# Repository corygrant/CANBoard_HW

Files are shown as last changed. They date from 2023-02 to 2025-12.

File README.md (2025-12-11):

# CANBoard_HW
CANBoard is a simple CAN enabled IO board, specifically designed to be used in devices like steering wheels/button boxes/panels/etc.

* 8 digital inputs
    * Ground switching
* 5 analog inputs
    * 5V max
* 4 digital outputs
    * Low side switch (open collector)
    * 0.5A max each
* STM32F303K8
* KiCad 7.0.0

# Goals
- Create a low cost device that my friends and I can use in our project cars
- Use components that are easily soldered by hand (hence 0805) and are preferably from my stock of frequently used parts (ex: LD1117S33CTR)
- Share my work with others for reference, inspiration or collaboration. 

If this project does help you in any way, I'd appreciate a message!

# [Store](https://dingo-electronics.square.site/product/canboard/3)

# Disclaimer
Please note that this product has been designed by a hobbyist, not a professional. It is intended for off-road and testing use only. Users should operate the product at their own discretion and risk. The designer explicitly disclaims any responsibility for damage or injury that may result from the use of this product.

# Schematic
[Schematic PDF](/Export/V2/CANBoard_HW_V2.pdf)

# DBC

DBC file can be found [here](https://github.com/corygrant/CANBoard_FW/tree/main/dbc)

# BOM

[Interactive BOM](https://htmlpreview.github.io/?https://github.com/corygrant/CANBoard_HW/blob/main/docs/bom/ibom.html)

# Jumpers
**CAN Term** : Soldering this jumper enables the 120 ohm terminating resistor across CANL/CANH

**CAN ID Jumpers 1 and 2** : Soldering these jumpers allows different base CAN IDs to be selected when using multiple CANBoards in the same bus
| 1 | 2 | Base CAN ID (Hex)|
| --- | --- | ----- |
| Open | Open | 0x640 |
| Closed | Open | 0x650 |
| Open | Closed | 0x660 |
| Closed | Closed | 0x670 |

# Firmware
[CANBoard firmware](https://github.com/corygrant/CANBoard_FW)

# Updating Firmware
Use [Tag Connect TC2030 cable](https://www.tag-connect.com/product/tc2030-ctx-nl-stdc14-for-use-with-stm32-processors-with-stlink-v3) 

# Images
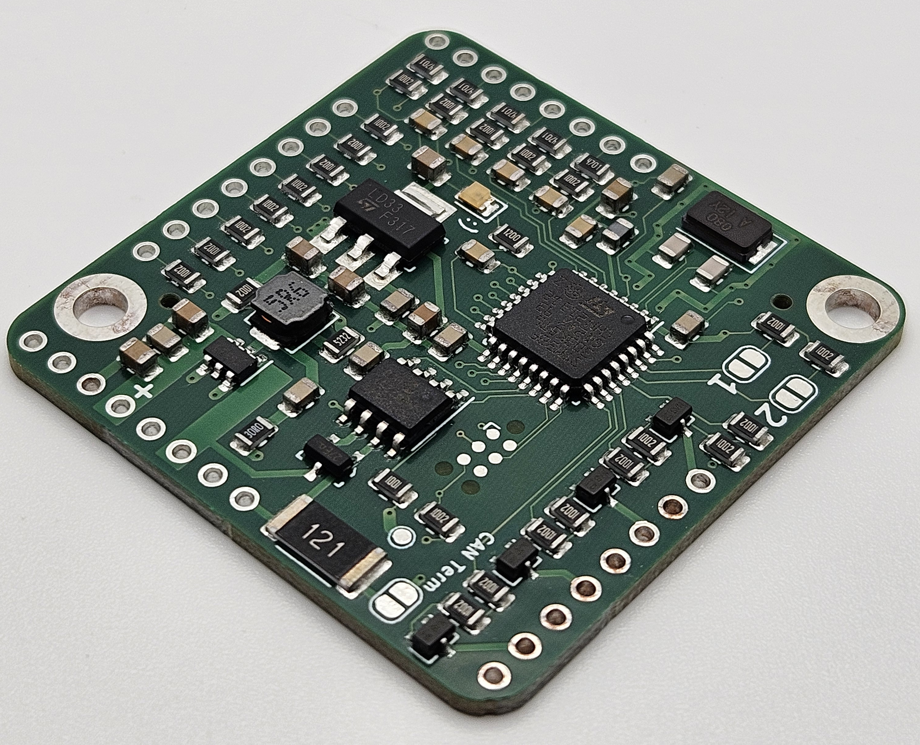
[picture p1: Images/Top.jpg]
Top


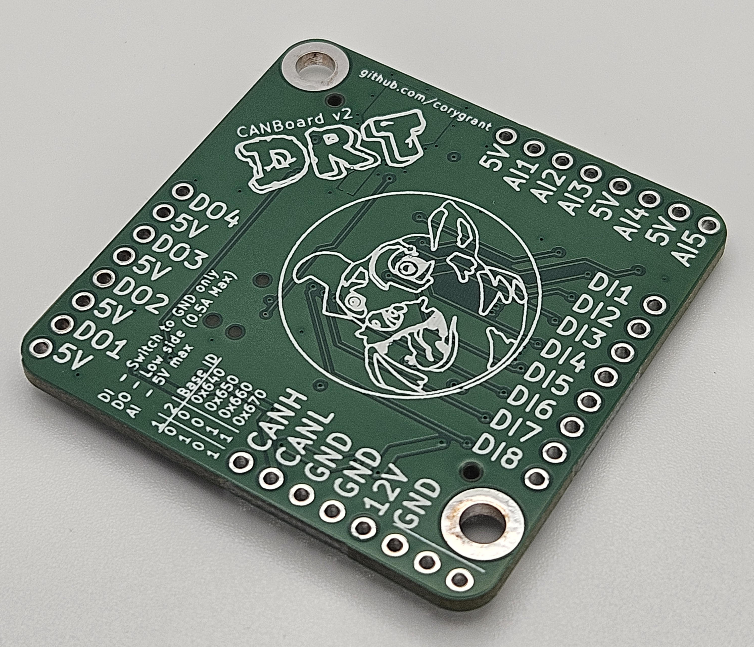
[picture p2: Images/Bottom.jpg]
Bottom


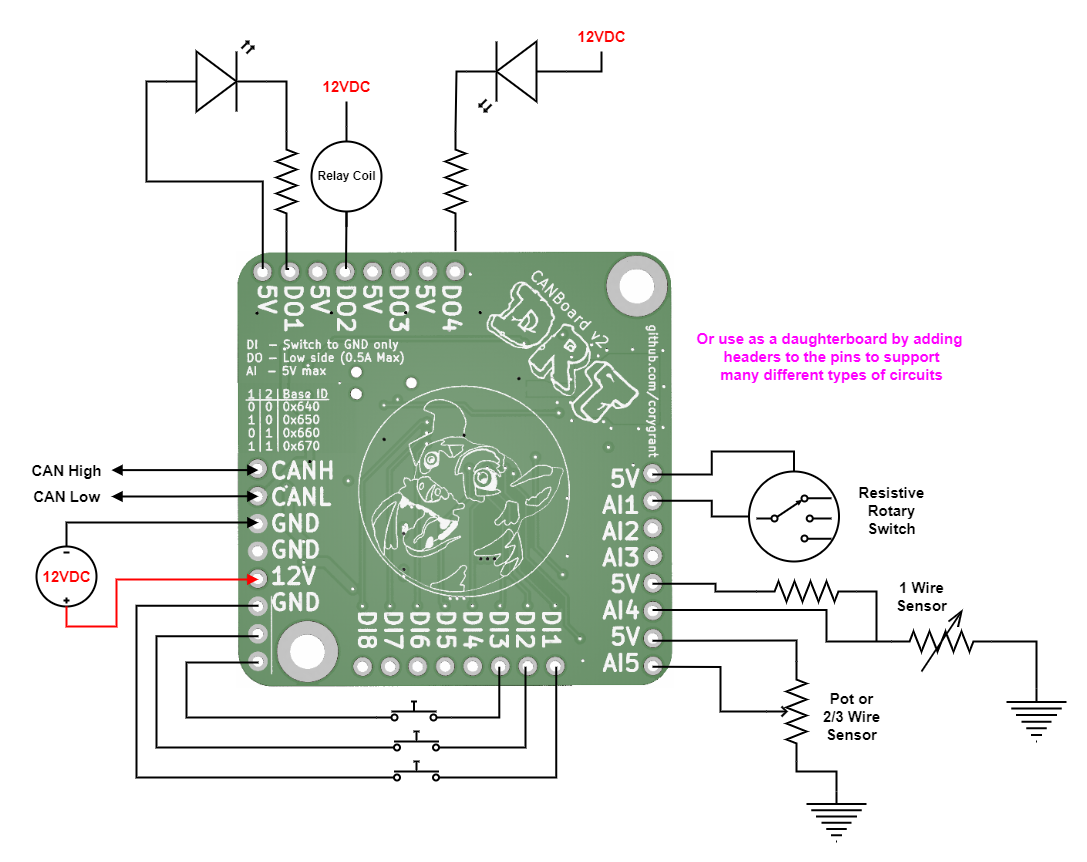
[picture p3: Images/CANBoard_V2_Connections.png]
Connections


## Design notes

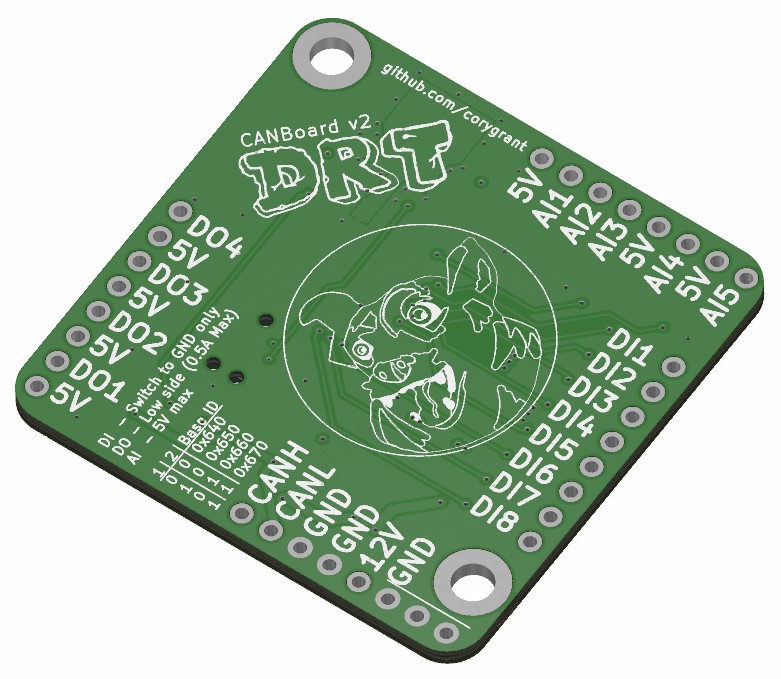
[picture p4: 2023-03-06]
Images/CANBoard_Bottom.jpg

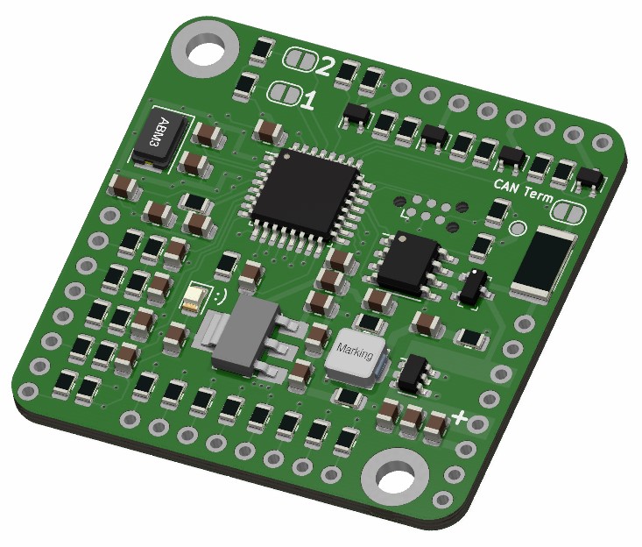
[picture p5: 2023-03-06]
Images/CANBoard_Top.jpg

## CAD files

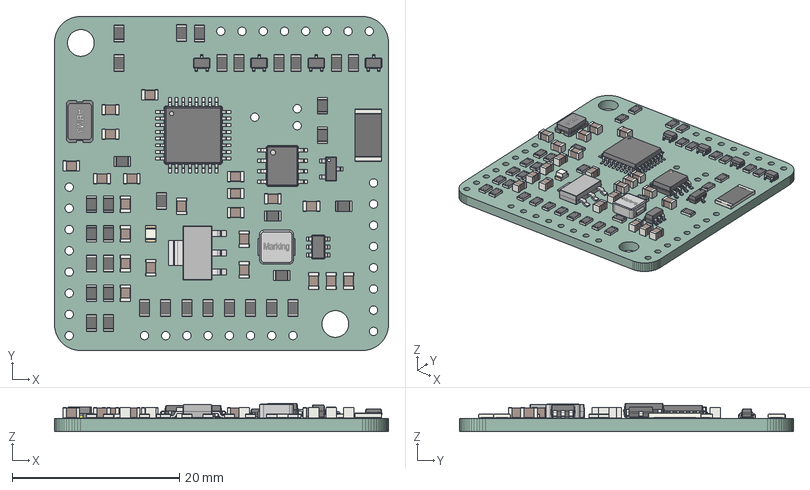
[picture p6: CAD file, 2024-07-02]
Export/V2/CANBoard_V2.step
40.0 x 40.0 x 3.38 mm
PCB

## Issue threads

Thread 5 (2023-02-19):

we have JLC BOM but not JLC placement file

rusefillc, 2023-02-19:
JLCPCB assembly takes gerbers, BOM and CPL for placement file

looks like placement file could be missing?

I know there is a minor drama between kicad export and JLC formats I vaguely remember people have to edit columns manually or use magic scripts let me know if I should poke people for more details

Closed 2023-02-19.

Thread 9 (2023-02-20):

Sad face: BOM not complete or JLC bug?

rusefillc, 2023-02-20:
JLC does not show LED and some random components are missing like digital resistors and output transistors? Is that a JLC render error or BOM is not full?

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

rusefillc, 2023-02-20:
PS: XLS file format is evil, CSV so much cooler for BOM - no need for weird tools and better git diffs

rusefillc, 2023-02-21:
```
Hi Andrey ,

Hope this mail finds you well.

After checking, unfortunately,  those components for the assembly had already been prepared on 2023-02-20.

In this case, I'm afraid it's just too late to cancel the assembly now due to process problem.

Please check if you could hand solder the missing parts by yourself this time?

Many thanks for your kind understanding.

Best regards,

Patrick
```

Closed 2023-02-21.

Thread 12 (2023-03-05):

Something EN pin

rusefillc, 2023-03-05:
@corygrant knows

corygrant, 2023-03-06:
One of the PCBs @rusefillc got from JLCPCB had a strange issue where the EN pin on the TPS56339DDCR (U1) buck converter had a 2mohm resistance to ground.
The EN pin should be completely floating (see section 7.3.2 of the datasheet).
This led to lots of power issues:
- Power not turning on
- Power fluctuating
- Lots of noise from the board
- Power only turning on when touching the EN pin with my finger

To fix this I cut and removed the pin and now the power is stable.
I'll update the PCB to remove the pad for EN (pin 5).

Closed 2023-03-06.

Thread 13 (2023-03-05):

blinking status LED

rusefillc, 2023-03-05:
Between #12 and else a blinking LED gives very clear confirmation of life

rusefillc, 2023-03-05:
Would that mean going to next pin count package?

corygrant, 2023-03-06:
Yes currently with the LQFP package we're maxed out on outputs

Closed 2024-07-17.

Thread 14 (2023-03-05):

By the way why F3?

rusefillc, 2023-03-05:
why F3 not F103 or else?

rusefillc, 2023-03-05:
Reasons I am asking:
* I am unhappy with $11.21 price
* I am unhappy with availability - note zero stock today assuming I search right

https://jlcpcb.com/partdetail/Stmicroelectronics-STM32F303K8T6/C118318

corygrant, 2023-03-06:
I can't remember exactly why I selected the F3.
Most likely because:
- The original design was done in fall 2020, so F3 stock wasn't an issue
- I had a handful of F303K8 leftover from another project

Lately I've been noticing some STM32s are easier to get than others and their product line is usually very pin compatible.
I'll see if there's an alternative part that could be easily swapped with no PCB changes.
If not, we can talk about updating to another part number. Possibly with more pins.

rusefillc, 2023-03-06:
> some STM32s are easier to get than others and their product line is usually very pin compatible.

let me mention "function-compatible replacements" i.e. clones
* TL,DR: at the moment I am very impressed with Geehy APM32 which JLCPCB has many

* at the pike of chip shortage we've tried GD32F1 - those needed a few lines of changes in the HAL. while it's only few lines it takes someone extremely highly qualified to locate what few lines to adjust. I've attempted to flash GD32F4 with as-is rusEFI and it did NOT fire up. overall GD32 is known to be close but not compatible
* now comes Geehy APM32. Two data points for those
- i know an automotive produce where they have simply replaced stm32f4 with apm32f4 and they claim zero firmware changes
- my own testing so far rusEFI firmware has started on apm32f4 and even USB connectivity was running! well, at the moment we've only tested flash, GPIO and USB but that's quite impressive

that's for apm32f4 open question how that translates to apm32f1 also open question why I am so fascinated by those alternatives. I guess I am addicted to the $2 price tag.

corygrant, 2023-03-06:
It seems like we're starting to come up out of the part shortage pit of despair, so hopefully JLC/LCSC will have things in stock soon.

Once you filter the ST catalog by LQFP32 and CAN you're left with only a couple of options, but most of them are available in the US:
- STM32F303K6 ($7.19)
- STM32F303K8 ($6.85)
- STM32F334K6 ($6.85)
- STM32F334K8 ($6.62)

Maybe ST is giving Digikey/Mouser/etc. preference and shipping to them first?
I think once the inventory starts hitting LCSC their prices will go down to similar levels.

pknetworksolutions, 2023-03-18:
Just got my board prep, with all the components needed. Just fill up your parts library and you can use them after that for the assembly

Luckey1996, 2024-01-17:
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

I was designing my product by using APM32F003 to replace STM8 and turns out the result was good. I have the same feeling that why not using Geehy with a extremely low price and good compatibility. Do you use already APM32F1 on your design and production? I want to know whether there are anything I need to prepare before the Mass Production. Look forward to your reply.

rusefillc, 2024-01-17:
> Do you use already APM32F1 on your design and production?

with stm32f4 prices going down at this point I am back to 100% stm32
* lack of USB DFU is a usability pain
* what we've designed as most budget unit turned to be unreliable with apm32f4 while stm32f4 is happy no idea what's root cause

Closed 2024-07-17.

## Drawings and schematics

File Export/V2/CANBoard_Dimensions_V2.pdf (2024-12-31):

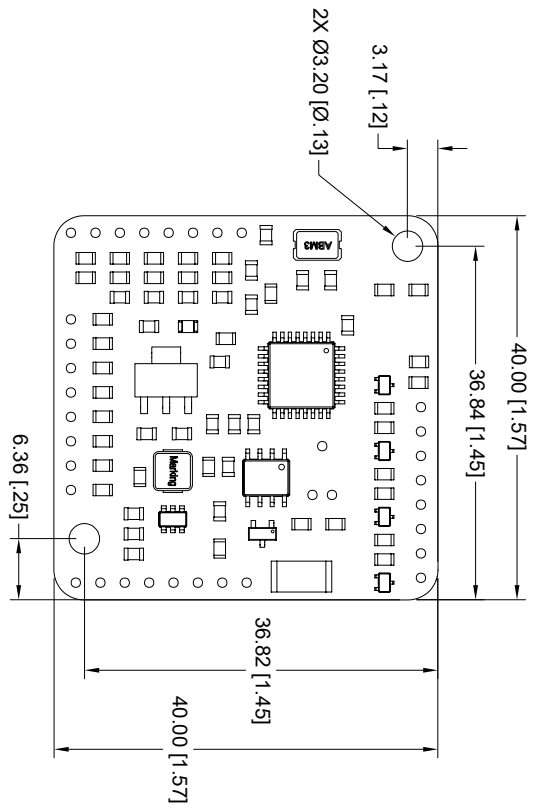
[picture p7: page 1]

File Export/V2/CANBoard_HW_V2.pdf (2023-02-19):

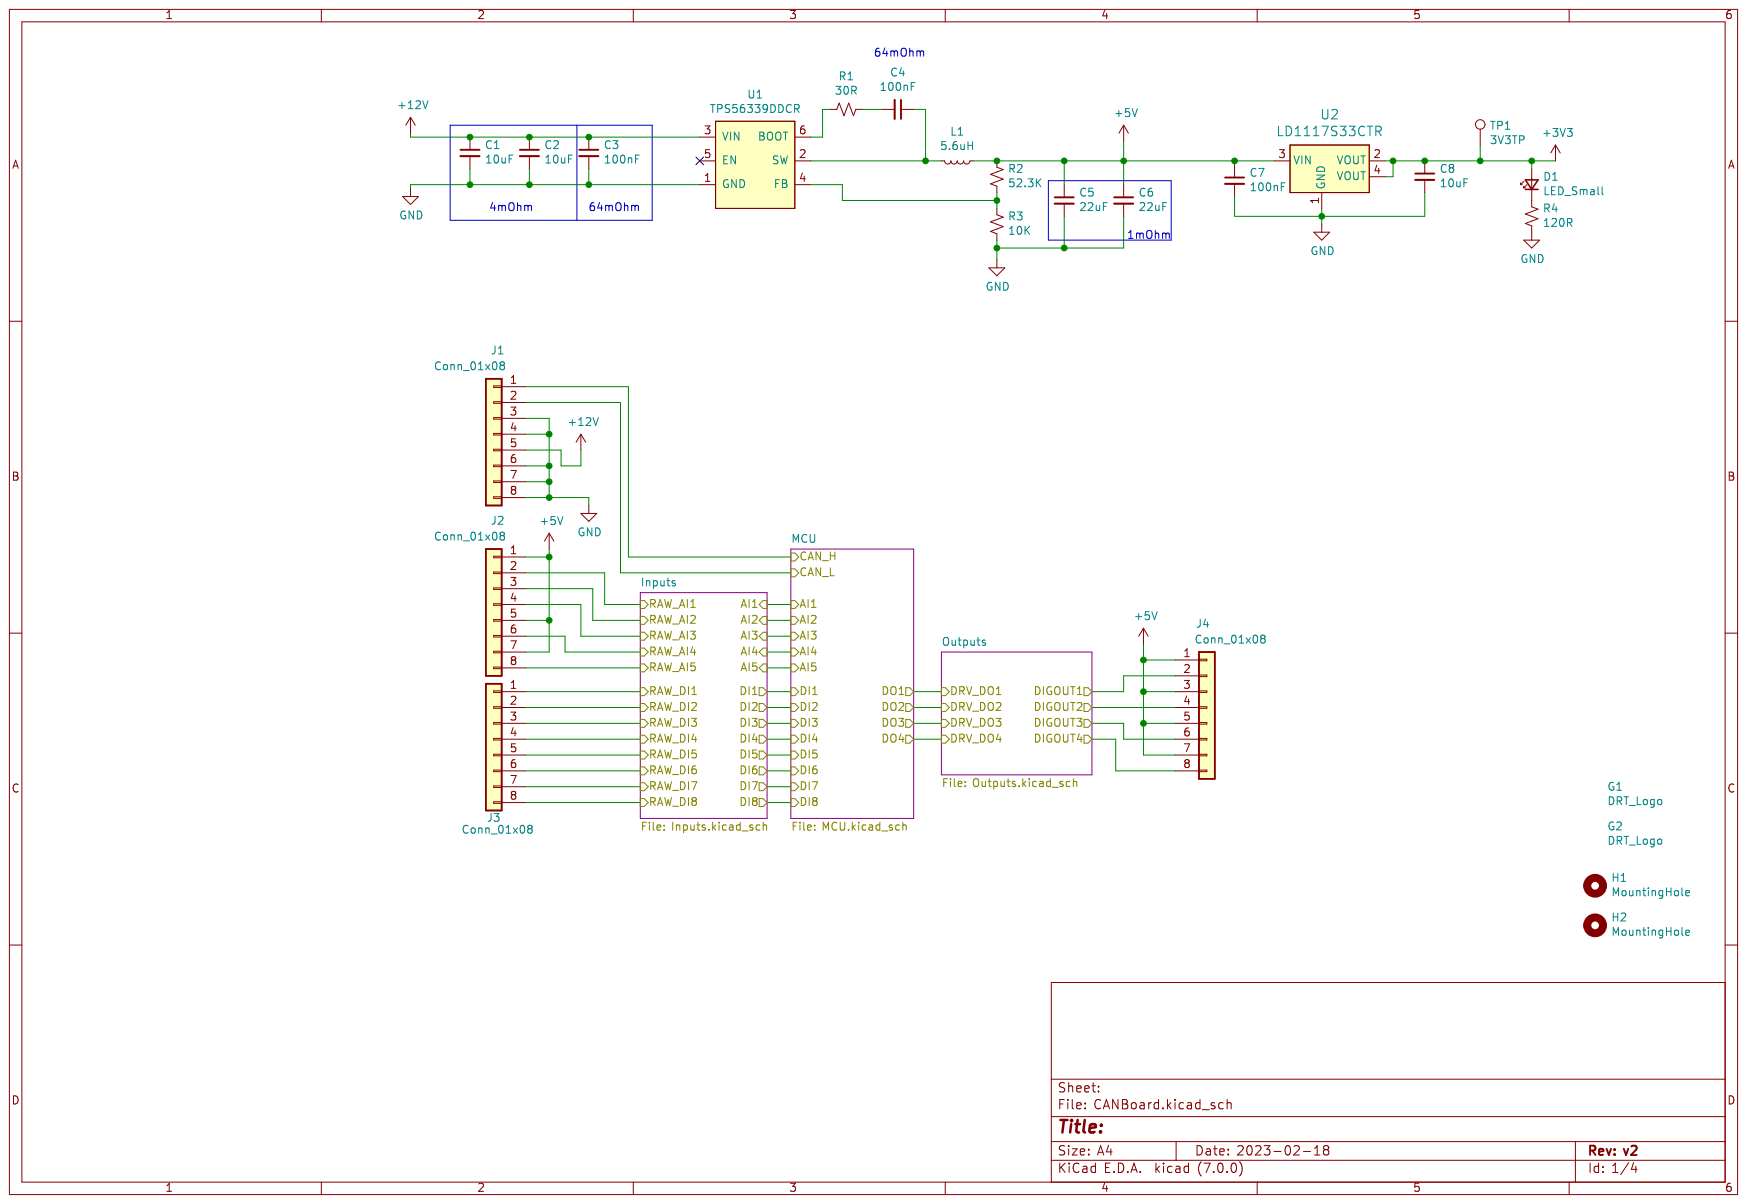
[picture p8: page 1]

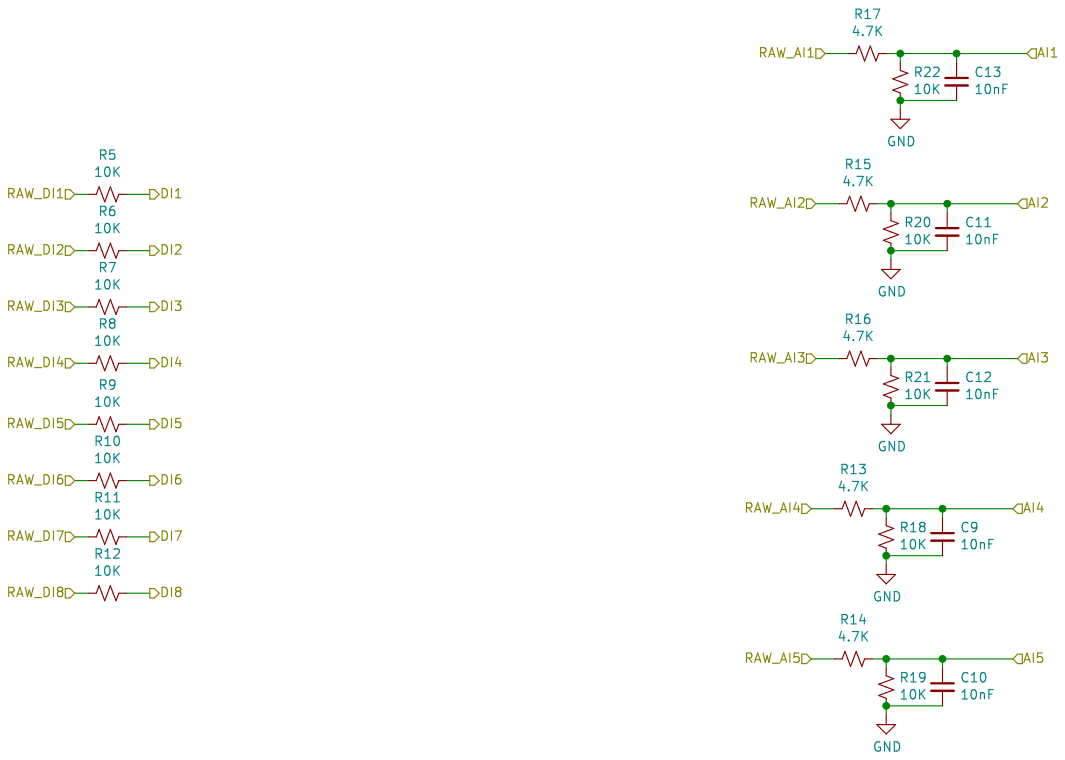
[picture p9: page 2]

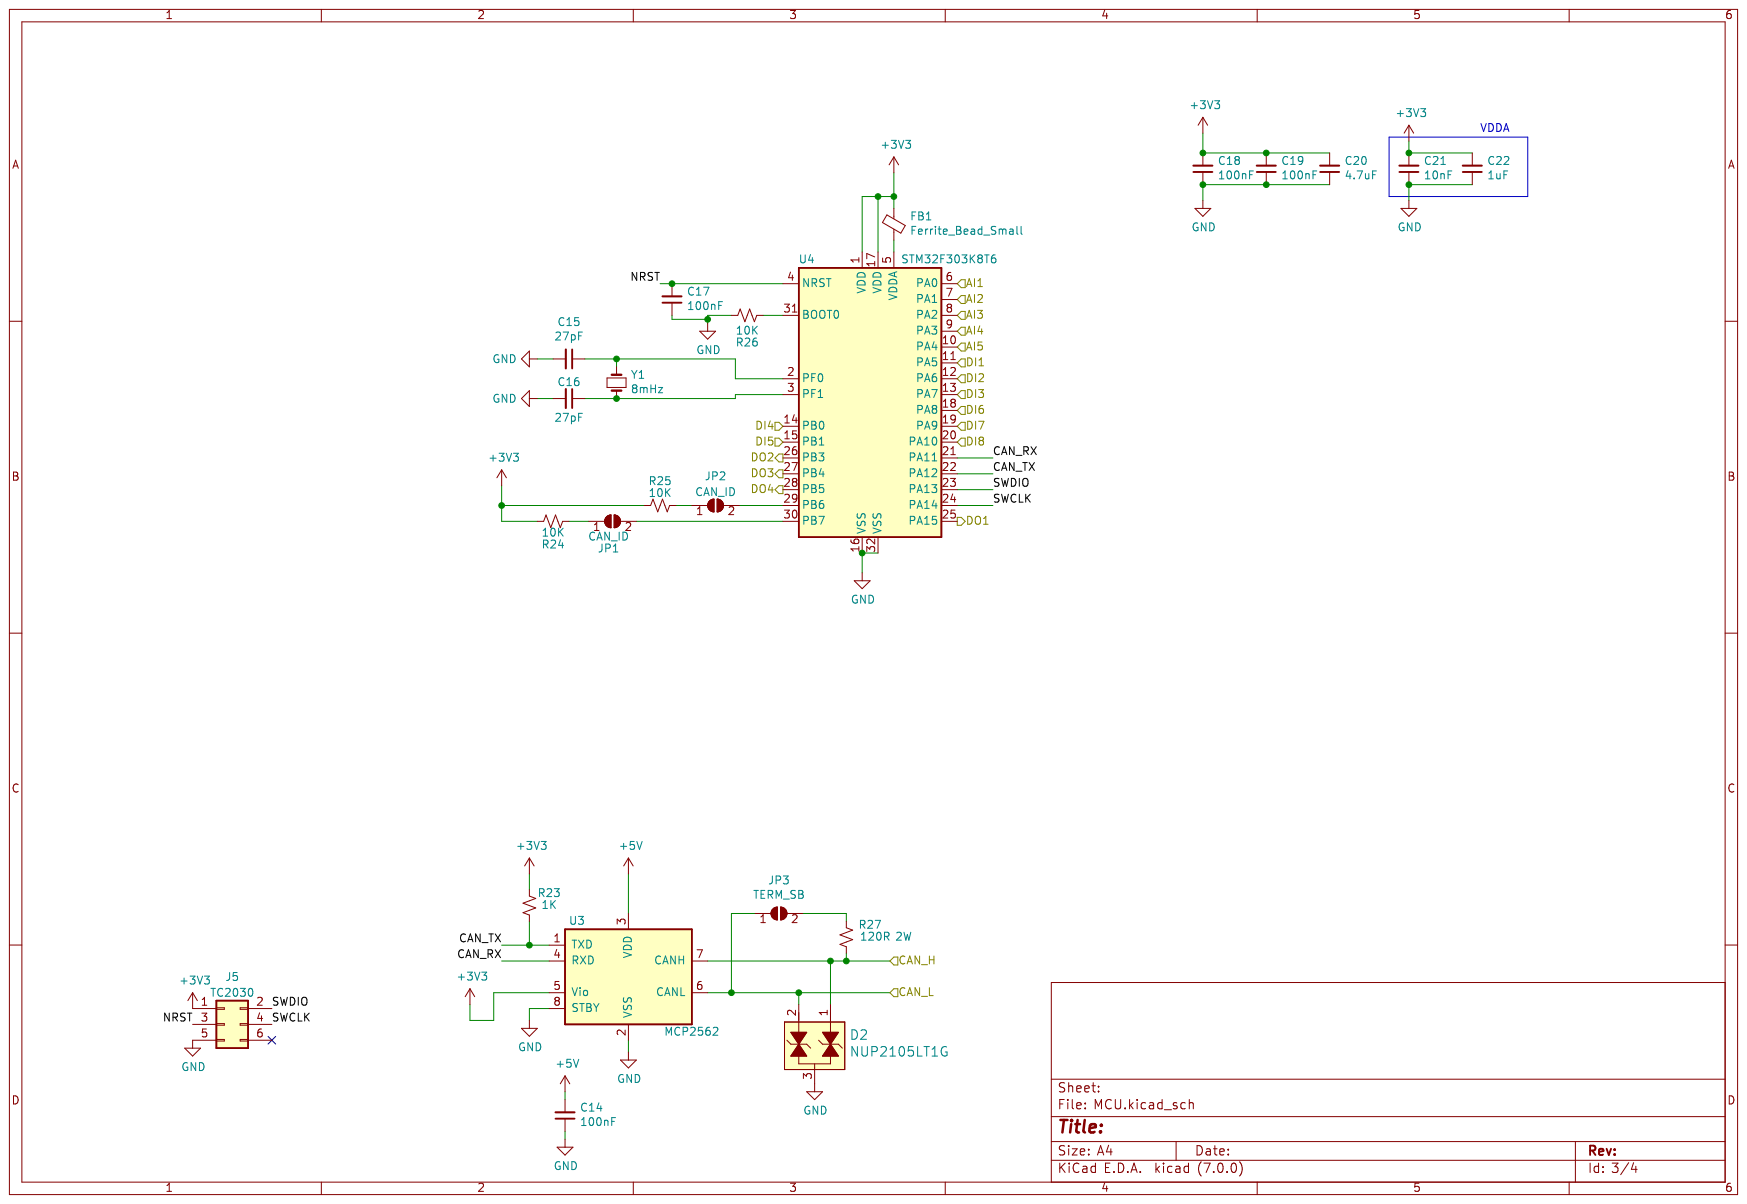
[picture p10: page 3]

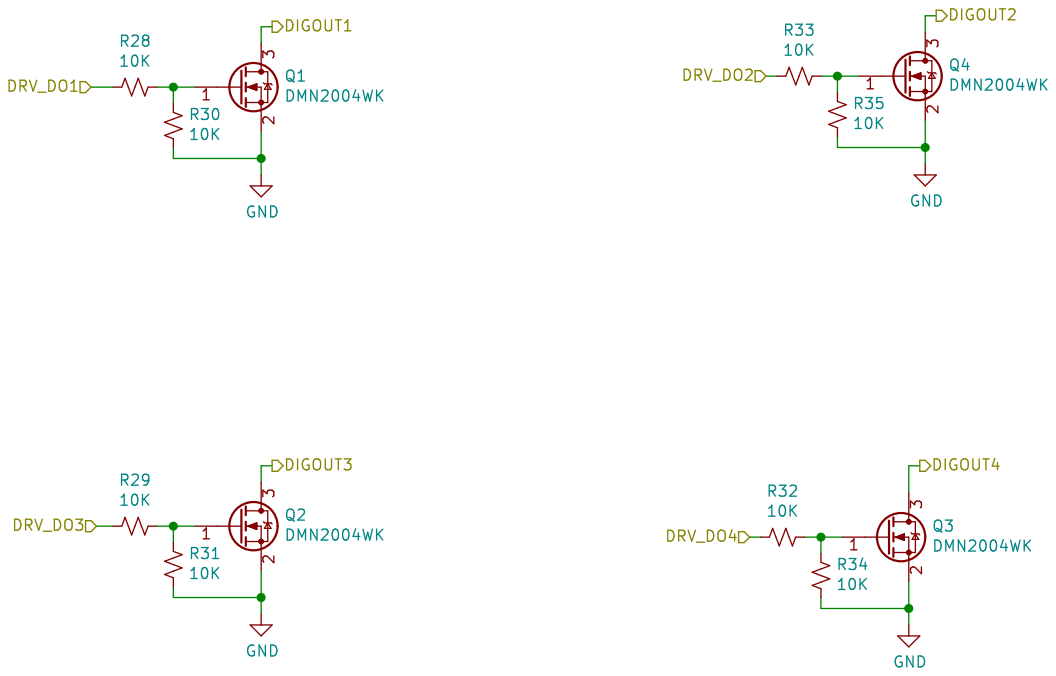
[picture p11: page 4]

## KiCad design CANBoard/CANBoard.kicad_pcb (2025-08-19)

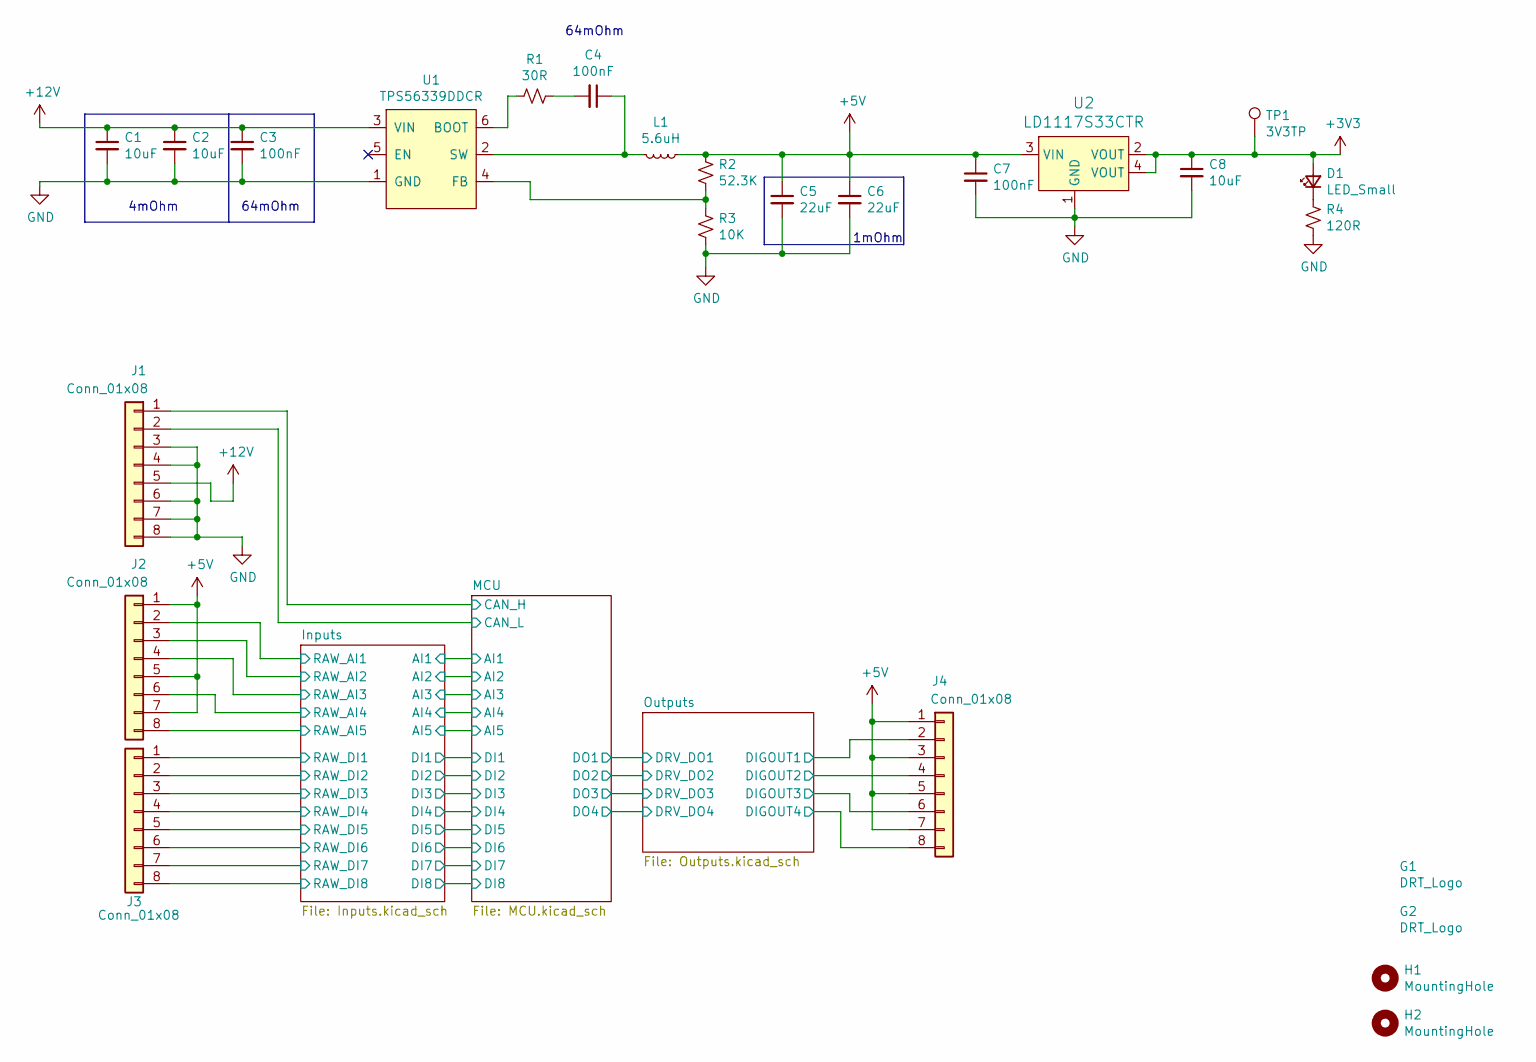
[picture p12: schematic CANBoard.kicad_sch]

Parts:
C1, C2, C8: 10uF; C_0805_2012Metric; Digi-Key_PN 490-10748-1-ND
C3, C4, C7: 100nF; C_0805_2012Metric; Digi-Key_PN 399-1169-1-ND
C5, C6: 22uF; C_0805_2012Metric; Digi-Key_PN 445-14560-1-ND
D1: LED_Small; LED_0805_2012Metric; Digi-Key_PN 475-2560-1-ND
G1: DRT_Logo; DRTLogo
G2: DRT_Logo; DingoFaceNoFill
H1, H2: MountingHole; MountingHole_3.2mm_M3_DIN965_Pad
J1, J2, J3, J4: Conn_01x08; PinHeader_1x08_P2.54mm_Vertical
L1: 5.6uH; Wuerth_LHMI; Digi-Key_PN 732-3339-1-ND
R1: 30R; R_0805_2012Metric; Digi-Key_PN RR12Q30DCT-ND
R2: 52.3K; R_0805_2012Metric; Digi-Key_PN P52.3KCCT-ND
R3: 10K; R_0805_2012Metric; Digi-Key_PN 311-10.0KCRDKR-ND
R4: 120R; R_0805_2012Metric; Digi-Key_PN 311-120CRCT-ND
TP1: 3V3TP; TestPoint_Pad_D1.0mm
U1: TPS56339DDCR; SOT-23-6_NoPin5; Digi-Key_PN 296-53568-1-ND
U2: LD1117S33CTR; SOT-223; MPN LD1117S33CTR; Digi-Key_PN 497-1241-1-ND

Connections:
+3V3: C8.1, D1.2 (A), TP1.1, U2.2 (VOUT), U2.4 (VOUT); also elsewhere on the board
+5V: C5.1, C6.1, C7.1, J2.1, J2.5, J2.7, J4.1, J4.3, J4.5, J4.7, L1.1, R2.2, U2.3 (VIN); also elsewhere on the board
+12V: C1.1, C2.1, C3.1, J1.5, U1.3 (VIN)
/Inputs/RAW_AI1: J2.2; also elsewhere on the board
/Inputs/RAW_AI2: J2.3; also elsewhere on the board
/Inputs/RAW_AI3: J2.4; also elsewhere on the board
/Inputs/RAW_AI4: J2.6; also elsewhere on the board
/Inputs/RAW_AI5: J2.8; also elsewhere on the board
/Inputs/RAW_DI1: J3.1; also elsewhere on the board
/Inputs/RAW_DI2: J3.2; also elsewhere on the board
/Inputs/RAW_DI3: J3.3; also elsewhere on the board
/Inputs/RAW_DI4: J3.4; also elsewhere on the board
/Inputs/RAW_DI5: J3.5; also elsewhere on the board
/Inputs/RAW_DI6: J3.6; also elsewhere on the board
/Inputs/RAW_DI7: J3.7; also elsewhere on the board
/Inputs/RAW_DI8: J3.8; also elsewhere on the board
/MCU/CAN_H: J1.1; also elsewhere on the board
/MCU/CAN_L: J1.2; also elsewhere on the board
/Outputs/DIGOUT1: J4.2; also elsewhere on the board
/Outputs/DIGOUT2: J4.4; also elsewhere on the board
/Outputs/DIGOUT3: J4.6; also elsewhere on the board
/Outputs/DIGOUT4: J4.8; also elsewhere on the board
GND: C1.2, C2.2, C3.2, C5.2, C6.2, C7.2, C8.2, J1.3, J1.4, J1.6, J1.7, J1.8, R3.1, R4.1, U1.1 (GND), U2.1 (GND); also elsewhere on the board
unnamed: C4.2, R1.1
unnamed: D1.1 (K), R4.2
unnamed: R1.2, U1.6 (BOOT)
unnamed: R2.1, R3.2, U1.4 (FB)
unnamed: C4.1, L1.2, U1.2 (SW)

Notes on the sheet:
1mOhm
4mOhm
64mOhm

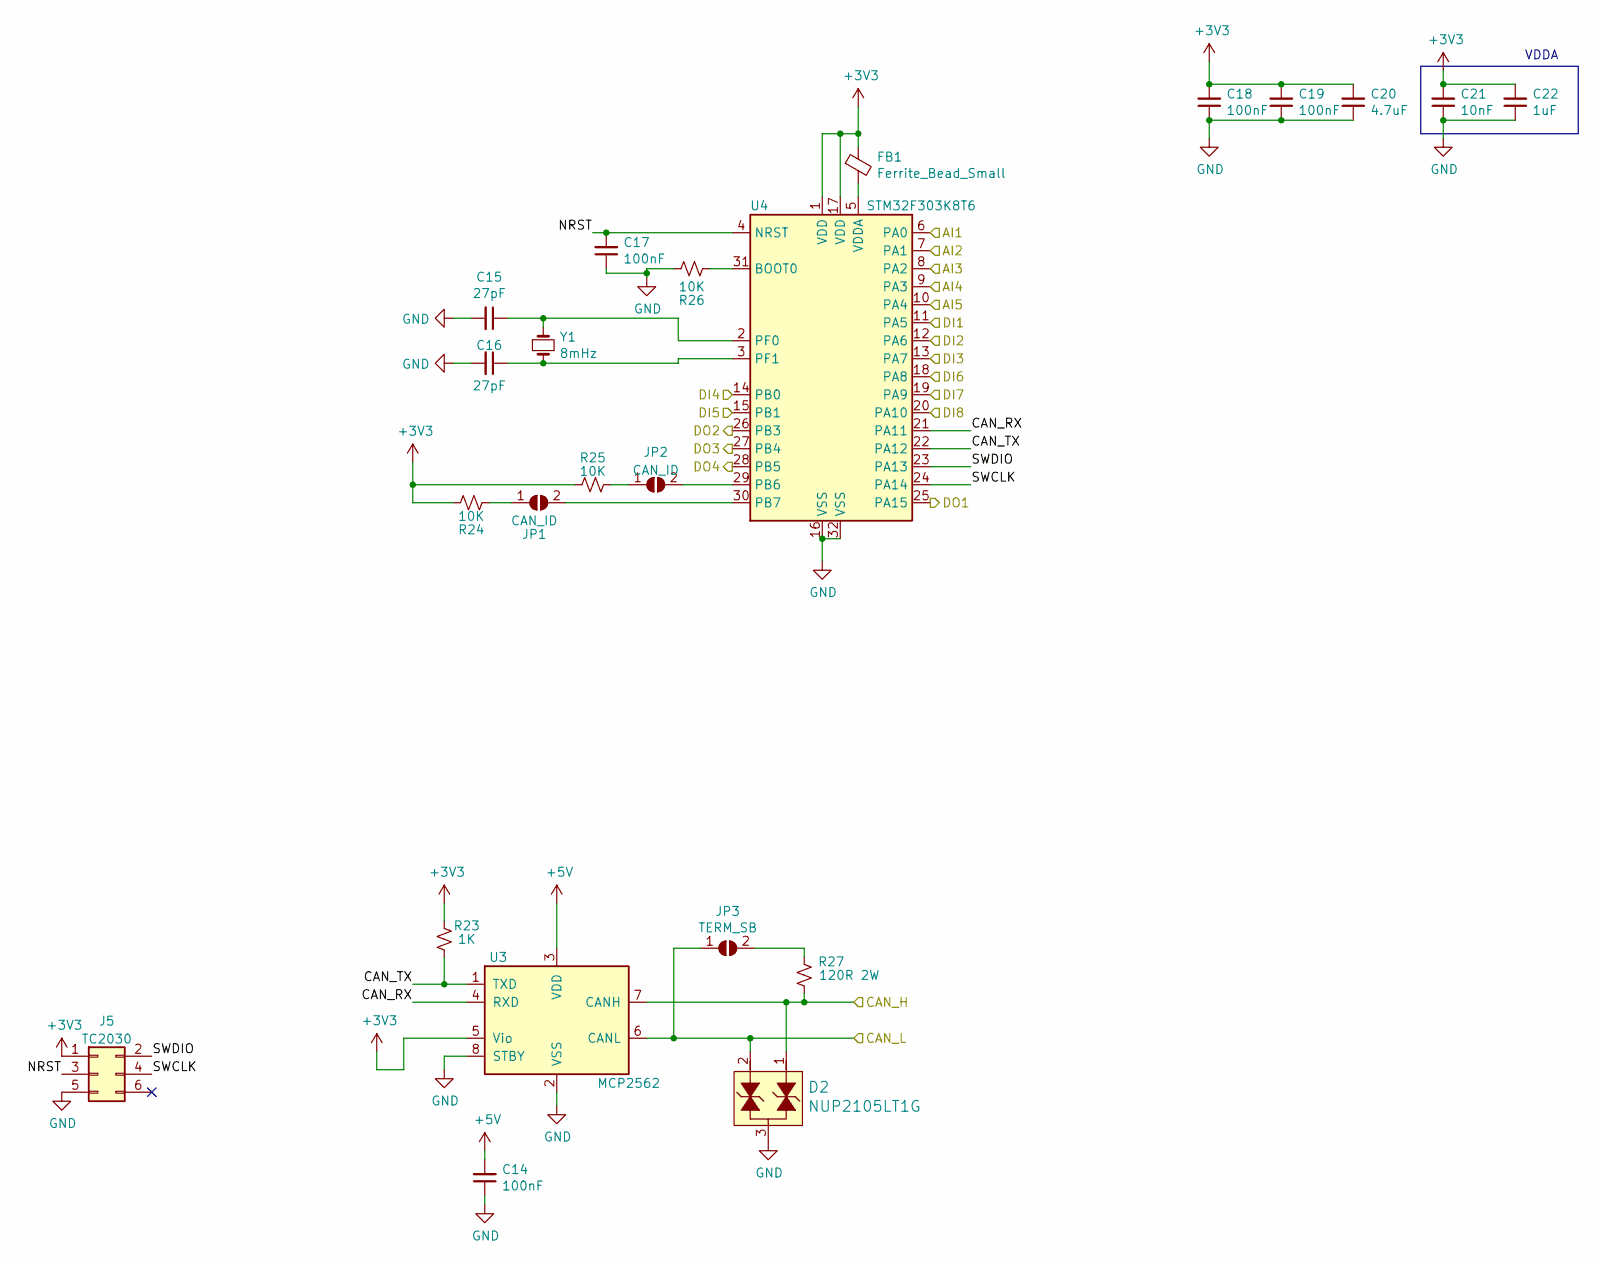
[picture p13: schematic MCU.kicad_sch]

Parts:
C14, C17, C18, C19: 100nF; C_0805_2012Metric; Digi-Key_PN 399-1169-1-ND
C15, C16: 27pF; C_0805_2012Metric; Digi-Key_PN 478-10518-1-ND
C20: 4.7uF; C_0805_2012Metric; Digi-Key_PN 1276-2873-1-ND
C21: 10nF; C_0805_2012Metric; Digi-Key_PN 311-1136-1-ND
C22: 1uF; C_0805_2012Metric; Digi-Key_PN 311-1365-1-ND
D2: NUP2105LT1G; SOT-23-3; MPN NUP2105LT1G; Digi-Key_PN NUP2105LT1GOSCT-ND
FB1: Ferrite_Bead_Small; R_0805_2012Metric; Digi-Key_PN 490-1054-1-ND
J5: TC2030; Tag-Connect_TC2030-IDC-NL_2x03_P1.27mm_Vertical
JP1, JP2: CAN_ID; SolderJumper-2_P1.3mm_Open_RoundedPad1.0x1.5mm
JP3: TERM_SB; SolderJumper-2_P1.3mm_Open_RoundedPad1.0x1.5mm
R23: 1K; R_0805_2012Metric; Digi-Key_PN 311-1.0KARCT-ND
R24, R25, R26: 10K; R_0805_2012Metric; Digi-Key_PN 311-10.0KCRDKR-ND
R27: 120R 2W; R_2512_6332Metric; Digi-Key_PN A116010CT-ND
U3: MCP2562; SOIC-8_3.9x4.9mm_P1.27mm; Digi-Key_PN MCP2562-H/SN-ND
U4: STM32F303K8T6; LQFP-32_7x7mm_P0.8mm; Digi-Key_PN 497-15828-ND
Y1: 8mHz; Crystal_SMD_5032-2Pin_5.0x3.2mm; Digi-Key_PN 535-10630-1-ND

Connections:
+3V3: C18.2, C19.2, C20.2, C21.2, C22.2, FB1.1, J5.1, R23.2, R24.2, R25.2, U3.5 (Vio), U4.1 (VDD), U4.17 (VDD); also elsewhere on the board
+5V: C14.2, U3.3 (VDD); also elsewhere on the board
/Inputs/AI1: U4.6 (PA0); also elsewhere on the board
/Inputs/AI2: U4.7 (PA1); also elsewhere on the board
/Inputs/AI3: U4.8 (PA2); also elsewhere on the board
/Inputs/AI4: U4.9 (PA3); also elsewhere on the board
/Inputs/AI5: U4.10 (PA4); also elsewhere on the board
/Inputs/DI1: U4.11 (PA5); also elsewhere on the board
/Inputs/DI2: U4.12 (PA6); also elsewhere on the board
/Inputs/DI3: U4.13 (PA7); also elsewhere on the board
/Inputs/DI4: U4.14 (PB0); also elsewhere on the board
/Inputs/DI5: U4.15 (PB1); also elsewhere on the board
/Inputs/DI6: U4.18 (PA8); also elsewhere on the board
/Inputs/DI7: U4.19 (PA9); also elsewhere on the board
/Inputs/DI8: U4.20 (PA10); also elsewhere on the board
/MCU/CAN_H: D2.1, R27.1, U3.7 (CANH); also elsewhere on the board
/MCU/CAN_L: D2.2, JP3.1 (A), U3.6 (CANL); also elsewhere on the board
/MCU/CAN_RX: U3.4 (RXD), U4.21 (PA11)
/MCU/CAN_TX: R23.1, U3.1 (TXD), U4.22 (PA12)
/MCU/DO1: U4.25 (PA15); also elsewhere on the board
/MCU/DO2: U4.26 (PB3); also elsewhere on the board
/MCU/DO3: U4.27 (PB4); also elsewhere on the board
/MCU/DO4: U4.28 (PB5); also elsewhere on the board
/MCU/NRST: C17.2, J5.3, U4.4 (NRST)
/MCU/SWCLK: J5.4, U4.24 (PA14)
/MCU/SWDIO: J5.2, U4.23 (PA13)
GND: C14.1, C15.2, C16.2, C17.1, C18.1, C19.1, C20.1, C21.1, C22.1, D2.3, J5.5, R26.2, U3.2 (VSS), U3.8 (STBY), U4.16 (VSS), U4.32 (VSS); also elsewhere on the board
unnamed: JP1.1 (A), R24.1
unnamed: JP1.2 (B), U4.30 (PB7)
unnamed: JP2.1 (A), R25.1
unnamed: JP2.2 (B), U4.29 (PB6)
unnamed: JP3.2 (B), R27.2
unnamed: R26.1, U4.31 (BOOT0)
unnamed: C15.1, U4.2 (PF0), Y1.1
unnamed: C16.1, U4.3 (PF1), Y1.2
unnamed: FB1.2, U4.5 (VDDA)

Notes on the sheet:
VDDA

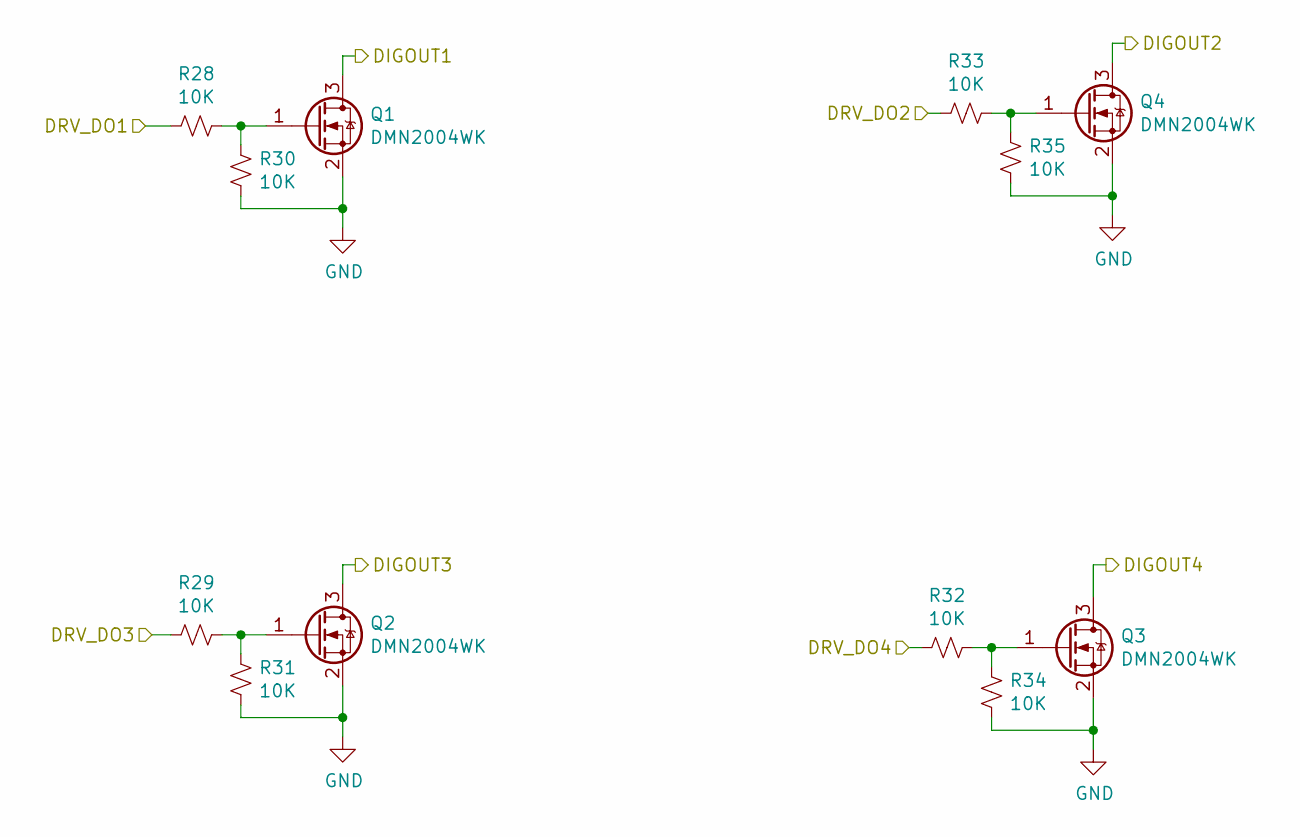
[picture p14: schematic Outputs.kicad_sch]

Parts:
Q1, Q2, Q3, Q4: DMN2004WK; SOT-323_SC-70; Digi-Key_PN DMN2004WKDICT-ND
R28, R29, R30, R31, R32, R33, R34, R35: 10K; R_0805_2012Metric; Digi-Key_PN 311-10.0KCRDKR-ND

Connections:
/MCU/DO1: R28.2; also elsewhere on the board
/MCU/DO2: R33.2; also elsewhere on the board
/MCU/DO3: R29.2; also elsewhere on the board
/MCU/DO4: R32.2; also elsewhere on the board
/Outputs/DIGOUT1: Q1.3 (D); also elsewhere on the board
/Outputs/DIGOUT2: Q4.3 (D); also elsewhere on the board
/Outputs/DIGOUT3: Q2.3 (D); also elsewhere on the board
/Outputs/DIGOUT4: Q3.3 (D); also elsewhere on the board
GND: Q1.2 (S), Q2.2 (S), Q3.2 (S), Q4.2 (S), R30.1, R31.1, R34.1, R35.1; also elsewhere on the board
unnamed: Q1.1 (G), R28.1, R30.2
unnamed: Q2.1 (G), R29.1, R31.2
unnamed: Q3.1 (G), R32.1, R34.2
unnamed: Q4.1 (G), R33.1, R35.2

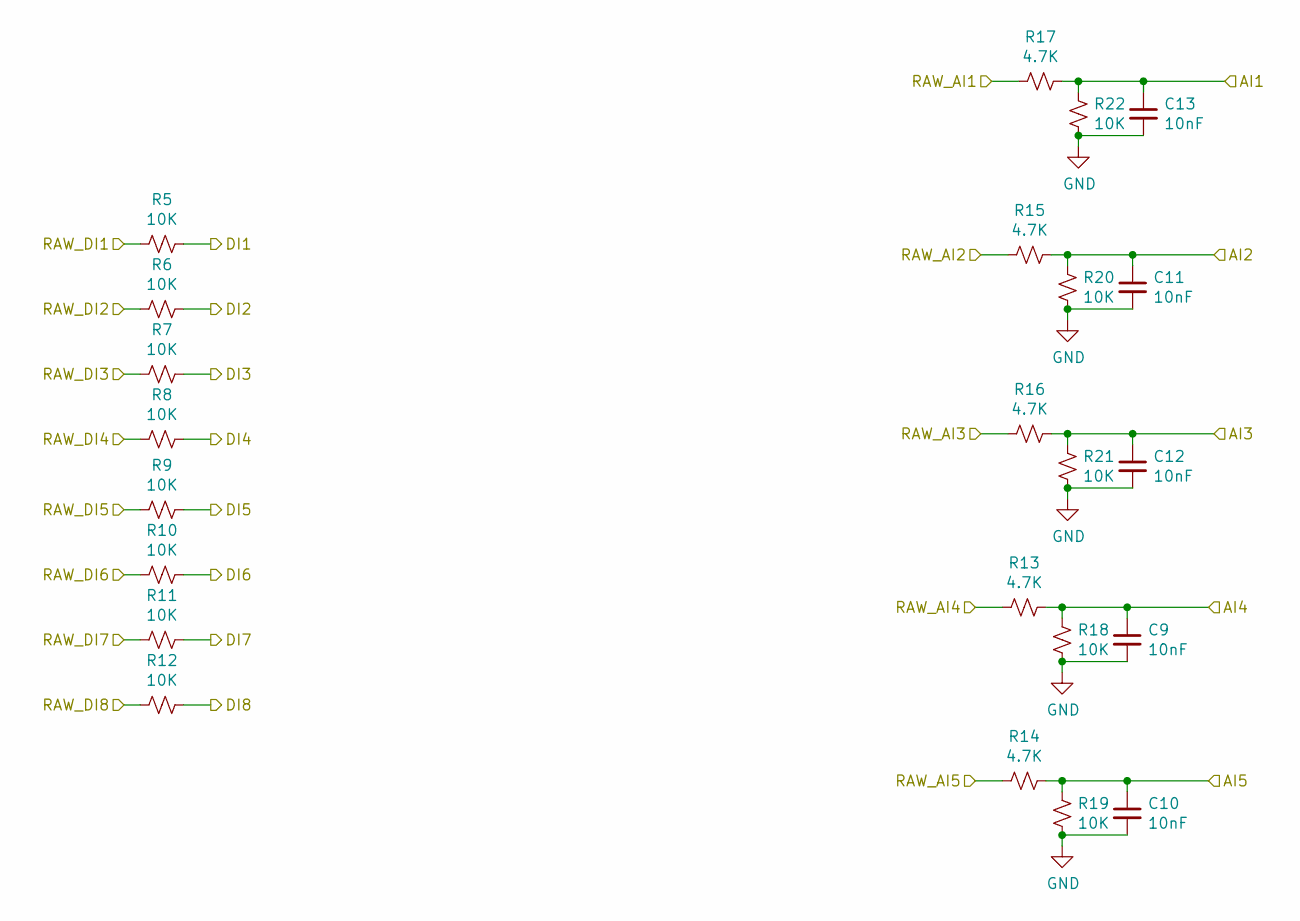
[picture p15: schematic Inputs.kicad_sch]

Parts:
C9, C10, C11, C12, C13: 10nF; C_0805_2012Metric; Digi-Key_PN 311-1136-1-ND
R5, R6, R7, R8, R9, R10, R11, R12, R18, R19, R20, R21, R22: 10K; R_0805_2012Metric; Digi-Key_PN 311-10.0KCRDKR-ND
R13, R14, R15, R16, R17: 4.7K; R_0805_2012Metric; Digi-Key_PN 311-4.70KCRCT-ND

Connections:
/Inputs/AI1: C13.1, R17.1, R22.2; also elsewhere on the board
/Inputs/AI2: C11.1, R15.1, R20.2; also elsewhere on the board
/Inputs/AI3: C12.1, R16.1, R21.2; also elsewhere on the board
/Inputs/AI4: C9.1, R13.1, R18.2; also elsewhere on the board
/Inputs/AI5: C10.1, R14.1, R19.2; also elsewhere on the board
/Inputs/DI1: R5.1; also elsewhere on the board
/Inputs/DI2: R6.1; also elsewhere on the board
/Inputs/DI3: R7.1; also elsewhere on the board
/Inputs/DI4: R8.1; also elsewhere on the board
/Inputs/DI5: R9.1; also elsewhere on the board
/Inputs/DI6: R10.1; also elsewhere on the board
/Inputs/DI7: R11.1; also elsewhere on the board
/Inputs/DI8: R12.1; also elsewhere on the board
/Inputs/RAW_AI1: R17.2; also elsewhere on the board
/Inputs/RAW_AI2: R15.2; also elsewhere on the board
/Inputs/RAW_AI3: R16.2; also elsewhere on the board
/Inputs/RAW_AI4: R13.2; also elsewhere on the board
/Inputs/RAW_AI5: R14.2; also elsewhere on the board
/Inputs/RAW_DI1: R5.2; also elsewhere on the board
/Inputs/RAW_DI2: R6.2; also elsewhere on the board
/Inputs/RAW_DI3: R7.2; also elsewhere on the board
/Inputs/RAW_DI4: R8.2; also elsewhere on the board
/Inputs/RAW_DI5: R9.2; also elsewhere on the board
/Inputs/RAW_DI6: R10.2; also elsewhere on the board
/Inputs/RAW_DI7: R11.2; also elsewhere on the board
/Inputs/RAW_DI8: R12.2; also elsewhere on the board
GND: C9.2, C10.2, C11.2, C12.2, C13.2, R18.1, R19.1, R20.1, R21.1, R22.1; also elsewhere on the board

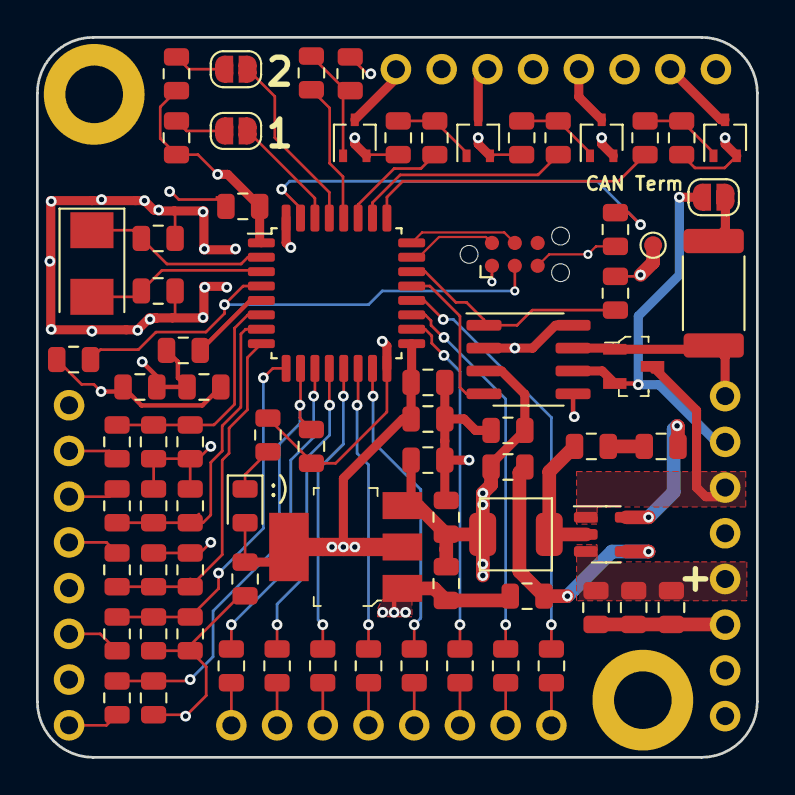
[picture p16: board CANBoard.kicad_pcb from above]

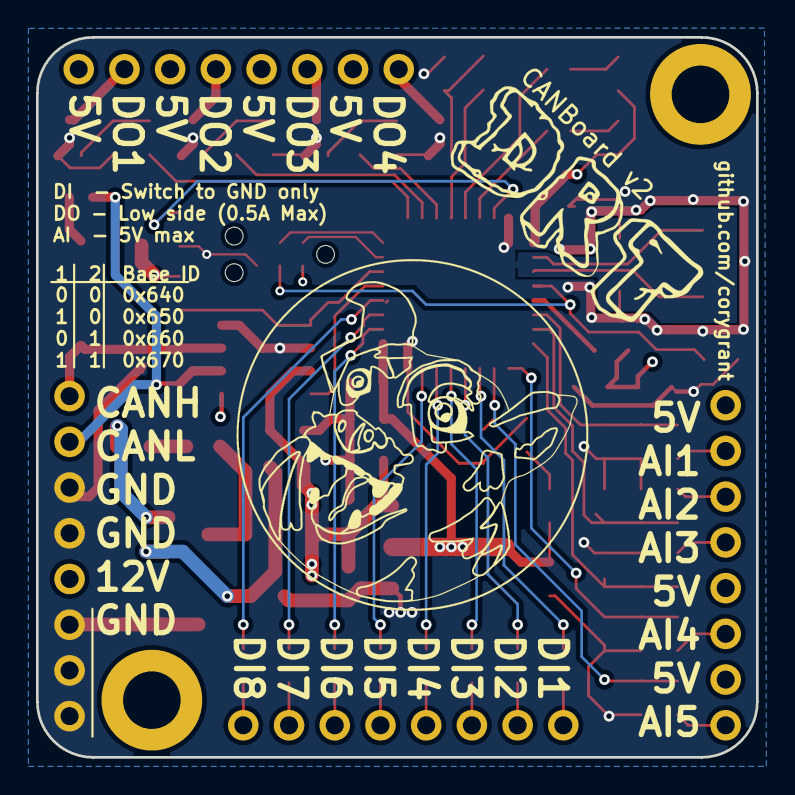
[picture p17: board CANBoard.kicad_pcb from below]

Board: 4 copper layers, 40.0 x 40.0 mm, 83 parts (2 on the bottom side), 63 nets.

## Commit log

2021-04-10 Reorganizing files
    [CANBoard-B_Cu.gbl, CANBoard-B_Mask.gbs, CANBoard-B_SilkS.gbo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]
2021-05-12 Swapped MCP2551 to MCP2562
    [CANBoard.kicad_pcb, MCU.sch]
2022-10-15 Kicad V6 updates
2022-12-13 Convert to kicad v6
    [CANBoard.kicad_pcb, CANBoard.kicad_sch, Inputs.kicad_sch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]
2023-02-18 V2 updates
    Removed FRAM, I2C and SWD pins. Added ID solder jumpers and Tag Connect
    [CANBoard.kicad_pcb, CANBoard.kicad_sch, Inputs.kicad_sch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]
2023-02-19 Updated outputs, added JLCPCB LCSC part nums
    [CANBoard-B_Cu.gbl, CANBoard-B_Mask.gbs, CANBoard-B_Paste.gbp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]
2023-02-19 Render missing component model
    [CANBoard.kicad_pcb]
2023-02-19 hopefully better placement for v1 gerbers?
2023-02-19 same gerbers are already present in CANBoard_HW_V2_gerbers.zip and I got confused already
    [CANBoard-B_Cu.gbl, CANBoard-B_Mask.gbs, CANBoard-B_Paste.gbp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]
2023-02-19 i see kicad 6
2023-02-19 second set of same exact individual files?
    [CANBoard-B_Cu.gbl, CANBoard-B_Mask.gbs, CANBoard-B_Paste.gbp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]
2023-02-19 Oops had .csv in the gitignore #5
    [CANBoard-top-pos.csv]
2023-02-20 Updated to Kicad 7, updated readme
    Changed Renders directory to Images
2023-02-21 Fixed JLCPCB file issues
    I had L1 set as THT, which left it out of the export. I also had the BOM grouped which didn't work with their import tool. #9
    [CANBoard.kicad_pcb, CANBoard_V2_BOM.csv, CANBoard_V2_BOM.xlsx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]
2023-03-06 #12 Removed U1 EN pin 5, updated documentation
    [CANBoard.kicad_pcb, CANBoard.kicad_sch]
2023-08-24 Update PartPlacement.jpg
    Power LED was backwards
2024-04-03 Updated JLC inductor part number
    [CANBoard.kicad_sch, CANBoard_V2_BOM.csv]
2024-07-02 Added step model
    [CANBoard_V2.step]
2024-09-06 Updated to Kicad 8
    [CANBoard.kicad_pcb, CANBoard.kicad_sch, Inputs.kicad_sch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]
2025-04-24 update to kicad 9.0.1
    [CANBoard.kicad_pcb, CANBoard.kicad_sch, Inputs.kicad_sch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]
2025-08-19 move footprints to project library
    [CANBoard.kicad_pcb, CANBoard.kicad_sch, MCU.kicad_sch]
2025-12-11 Fix link to Interactive BOM in README.md
